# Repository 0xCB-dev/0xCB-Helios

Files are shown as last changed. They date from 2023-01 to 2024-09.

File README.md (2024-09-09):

# 0xCB-Helios

### RP2040 pro micro drop in

| Licence | OSHWA |
| :---: | :---: |
|  | (https://certification.oshwa.org/de000131.html) |

### Official vendors

Purchasing Helios from any vendors listed here directly supports our work. Helios controllers sourced from vendors not listed here and not produced by us will not receive the same level of support and may have varying degrees of quality.

### EU:

Germany: [KeebSupply](https://keeb.supply/products/0xcb-helios)

Germany: [Keycapsss](https://keycapsss.com/keyboard-parts/mcu-controller/257/0xcb-helios-pro-micro/elite-c-compatible-microcontroller-with-rp2040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)

### North America:

America: [Ringer Keys](https://ringerkeys.com/collections/modders-tools/products/0xcb-helios)

Canada: [RNDKBD](https://rndkbd.com/products/0xcb-helios-microcontroller)

#### Flashing

- `qmk clone`
- `cd qmk_firmware`
- To go to bootloader press the reset button longer than 500ms and release. Alternatively you can short the RST pin to GND, as it's wired to the reset button.
- `make 0xcb/helios:default:flash`

### Assembly

The PCBs are assembled at the fab with the production files located in the /kikit/prod/ dir.

### Integration in your own design

We strongly recommend that you take a look at [ebastler's symbol and footprint library for KiCAD](https://github.com/ebastler/marbastlib).
The Helios files are located in the "promicroish" folder with various mounting options to choose from. 
If you need any help integrating Helios into your keyboard PCB, please feel free to contact us.

### PCB

KiCad 7 stable

[Schematic](https://github.com/0xCB-dev/0xcb-Helios/blob/main/rev1.0/helios.pdf)

### Pinout

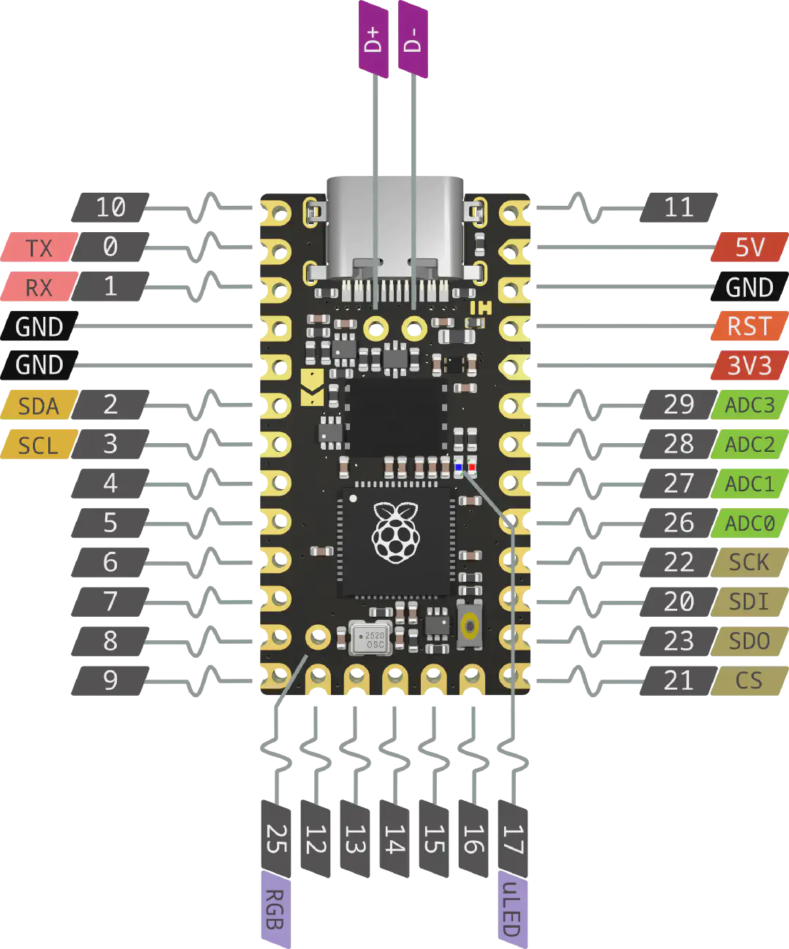
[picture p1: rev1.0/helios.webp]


| GPIO | F1 | F2 | F3 | F4 | F5  | F6 | F7 | F8 | F9 |
| ---- | --- | --- | --- | --- | --- | ---- | ---- | --- | --- |
| 0 | SPI0 RX  | UART0 TX  | I2C0 SDA | PWM0 A | SIO | PIO0 | PIO1 | | USB OVCUR DET |
| 1 | SPI0 CSn | UART0 RX  | I2C0 SCL | PWM0 B | SIO | PIO0 | PIO1 | | USB VBUS DET  |
| 2 | SPI0 SCK | UART0 CTS | I2C1 SDA | PWM1 A | SIO | PIO0 | PIO1 | | USB VBUS EN |
| 3 | SPI0 TX  | UART0 RTS | I2C1 SCL | PWM1 B | SIO | PIO0 | PIO1 | | USB OVCUR DET |
| 4 | SPI0 RX  | UART1 TX  | I2C0 SDA | PWM2 A | SIO | PIO0 | PIO1 | | USB VBUS DET  |
| 5 | SPI0 CSn | UART1 RX  | I2C0 SCL | PWM2 B | SIO | PIO0 | PIO1 | | USB VBUS EN |
| 6 | SPI0 SCK | UART1 CTS | I2C1 SDA | PWM3 A | SIO | PIO0 | PIO1 | | USB OVCUR DET |
| 7 | SPI0 TX  | UART1 RTS | I2C1 SCL | PWM3 B | SIO | PIO0 | PIO1 | | USB VBUS DET  |
| 8 | SPI1 RX  | UART1 TX  | I2C0 SDA | PWM4 A | SIO | PIO0 | PIO1 | | USB VBUS EN |
| 9 | SPI1 CSn | UART1 RX  | I2C0 SCL | PWM4 B | SIO | PIO0 | PIO1 | | USB OVCUR DET |
| 10 | SPI1 SCK | UART1 CTS | I2C1 SDA | PWM5 A | SIO | PIO0 | PIO1 | | USB VBUS DET  |
| 11 | SPI1 TX  | UART1 RTS | I2C1 SCL | PWM5 B | SIO | PIO0 | PIO1 | | USB VBUS EN |
| 12 | SPI1 RX  | UART0 TX  | I2C0 SDA | PWM6 A | SIO | PIO0 | PIO1 | | USB OVCUR DET |
| 13 | SPI1 CSn | UART0 RX  | I2C0 SCL | PWM6 B | SIO | PIO0 | PIO1 | | USB VBUS DET  |
| 14 | SPI1 SCK | UART0 CTS | I2C1 SDA | PWM7 A | SIO | PIO0 | PIO1 | | USB VBUS EN |
| 15 | SPI1 TX  | UART0 RTS | I2C1 SCL | PWM7 B | SIO | PIO0 | PIO1 | | USB OVCUR DET |
| 16 | SPI0 RX  | UART0 TX  | I2C0 SDA | PWM0 A | SIO | PIO0 | PIO1 | | USB VBUS DET  |
| 17 | SPI0 CSn | UART0 RX  | I2C0 SCL | PWM0 B | SIO | PIO0 | PIO1 | | USB VBUS EN |
| 18 | SPI0 SCK | UART0 CTS | I2C1 SDA | PWM1 A | SIO | PIO0 | PIO1 | | USB OVCUR DET |
| 19 | SPI0 TX  | UART0 RTS | I2C1 SCL | PWM1 B | SIO | PIO0 | PIO1 | | USB VBUS DET  |
| 20 | SPI0 RX  | UART1 TX  | I2C0 SDA | PWM2 A | SIO | PIO0 | PIO1 | CLOCK GPIN0  | USB VBUS EN |
| 21 | SPI0 CSn | UART1 RX  | I2C0 SCL | PWM2 B | SIO | PIO0 | PIO1 | CLOCK GPOUT0 | USB OVCUR DET |
| 22 | SPI0 SCK | UART1 CTS | I2C1 SDA | PWM3 A | SIO | PIO0 | PIO1 | CLOCK GPIN1  | USB VBUS DET  |
| 23 | SPI0 TX  | UART1 RTS | I2C1 SCL | PWM3 B | SIO | PIO0 | PIO1 | CLOCK GPOUT1 | USB VBUS EN |
| 24 | SPI1 RX  | UART1 TX  | I2C0 SDA | PWM4 A | SIO | PIO0 | PIO1 | CLOCK GPOUT2 | USB OVCUR DET |
| 25 | SPI1 CSn | UART1 RX  | I2C0 SCL | PWM4 B | SIO | PIO0 | PIO1 | CLOCK GPOUT3 | USB VBUS DET  |
| 26 | SPI1 SCK | UART1 CTS | I2C1 SDA | PWM5 A | SIO | PIO0 | PIO1 | | USB VBUS EN |
| 27 | SPI1 TX  | UART1 RTS | I2C1 SCL | PWM5 B | SIO | PIO0 | PIO1 | | USB OVCUR DET |
| 28 | SPI1 RX  | UART0 TX  | I2C0 SDA | PWM6 A | SIO | PIO0 | PIO1 | | USB VBUS DET  |
| 29 | SPI1 CSn | UART0 RX  | I2C0 SCL | PWM6 B | SIO | PIO0 | PIO1 | | USB VBUS EN |

#### BOM:

| Comment | Designator | Footprint | LCSC |
| --- | --- | --- | --- |
| 4u7 | C1 | Capacitor_SMD:C_0402_1005Metric | C23733 |
| 10u | C2,C3,C4,C5 | Capacitor_SMD:C_0402_1005Metric | C15525 |
| 100n | C6,C11,C12,C13,C14,C15,C16,C17,C18,C19 | Capacitor_SMD:C_0402_1005Metric | C1525 |
| 15p | C7,C8 | Capacitor_SMD:C_0402_1005Metric | C1548 |
| 1u | C9,C10 | Capacitor_SMD:C_0402_1005Metric | C52923 |
| Power LED | D1 | Diode_SMD:D_0402_1005Metric | C130719  |
| User LED | D2 | Diode_SMD:D_0402_1005Metric | C130724  |
| PMEG2010BELD | D3 | 0xcb:SOD882D | C552820  |
| 500mA | F1 | Fuse:Fuse_0603_1608Metric | C210357  |
| 600R | FB1 | Resistor_SMD:R_0402_1005Metric | C160977  |
| USB_C_Receptacle_USB2.0 | J1 | 0xcb:GT-USB-7014C | C963373  |
| 2N7002VC- | Q1,Q2 | Package_TO_SOT_SMD:SOT-563 | C504145  |
| 10k | R1,R2,R3,R11,R17 | Resistor_SMD:R_0402_1005Metric | C25744 |
| 51K | R4,R5,R6 | Resistor_SMD:R_0402_1005Metric | C25794 |
| 5k1 | R7,R8,R16 | Resistor_SMD:R_0402_1005Metric | C25905 |
| 1K | R9 | Resistor_SMD:R_0402_1005Metric | C11702 |
| 1k | R10,R14,R15 | Resistor_SMD:R_0402_1005Metric | C11702 |
| 27R | R12,R13 | Resistor_SMD:R_0402_1005Metric | C25100 |
| SWITCH | SW1 | 0xcb:1.9x2.8mm SW | C589221  |
| USBLC6-2P6 | U1 | Package_TO_SOT_SMD:SOT-666 | C2827693 |
| TLV75533PDQNR | U2 | 0xcb:X2SON-4 | C2861882 |
| W25Q128JVPIQ | U3 | 0xcb:W25Q128JVPIQ | C190862  |
| RP2040 | U4 | Package_DFN_QFN:QFN-56-1EP_7x7mm_P0.4mm_EP3.2x3.2mm | C2040 |
| 74LVC1T45 | U5 | Package_TO_SOT_SMD:SOT-563 | C352970  |
| 12MHz | Y1 | Crystal:Crystal_SMD_2520-4Pin_2.5x2.0mm | C2149204 |

### Credits

The awesome one button reset circuit is based on the one used on the [Sea-picro](https://github.com/joshajohnson/sea-picro) by joshajohnson and this very well written [article](https://acheronproject.com/reset_article_1/reset_article_1/) by the Acheron Project.

Thank you! :heart:

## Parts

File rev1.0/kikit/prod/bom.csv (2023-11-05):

Comment | Designator | Footprint | LCSC
100n | C6,C11,C12,C13,C14,C15,C16,C17,C18,C19 | Capacitor_SMD:C_0402_1005Metric | C1525
USBLC6-2P6 | U1 | Package_TO_SOT_SMD:SOT-666 | C2827693
5.1k | R7,R8,R16 | Resistor_SMD:R_0402_1005Metric | C25905
1k | R9,R10,R14,R15 | Resistor_SMD:R_0402_1005Metric | C11702
12MHz | Y1 | Crystal:Crystal_SMD_2520-4Pin_2.5x2.0mm | C2149204
2N7002VC- | Q1,Q2 | Package_TO_SOT_SMD:SOT-563 | C504145
27 | R12,R13 | Resistor_SMD:R_0402_1005Metric | C25100
10k | R1,R2,R3,R11,R17 | Resistor_SMD:R_0402_1005Metric | C25744
Power LED | D1 | Diode_SMD:D_0402_1005Metric | C130719
10u | C2,C3,C4,C5 | Capacitor_SMD:C_0402_1005Metric | C15525
USB_C_Receptacle_USB2.0 | J1 | 0xcb:GT-USB-7014C | C963373
15p | C7,C8 | Capacitor_SMD:C_0402_1005Metric | C1548
1u | C9,C10 | Capacitor_SMD:C_0402_1005Metric | C52923
51k | R4,R5,R6 | Resistor_SMD:R_0402_1005Metric | C25794
User LED | D2 | Diode_SMD:D_0402_1005Metric | C130724
4.7u | C1 | Capacitor_SMD:C_0402_1005Metric | C23733
500mA | F1 | Fuse:Fuse_0603_1608Metric | C210357
PMEG2010BELD | D3 | 0xcb:SOD882D | C552820
600R | FB1 | Resistor_SMD:R_0402_1005Metric | C160977
TLV75533PDQNR | U2 | 0xcb:X2SON-4 | C2861882
74LVC1T45 | U5 | Package_TO_SOT_SMD:SOT-563 | C352970
W25Q128JVPIQ | U3 | 0xcb:W25Q128JVPIQ | C190862
SWITCH | SW1 | 0xcb:1.9x2.8mm SW | C589221
RP2040 | U4 | Package_DFN_QFN:QFN-56-1EP_7x7mm_P0.4mm_EP3.2x3.2mm | C2040

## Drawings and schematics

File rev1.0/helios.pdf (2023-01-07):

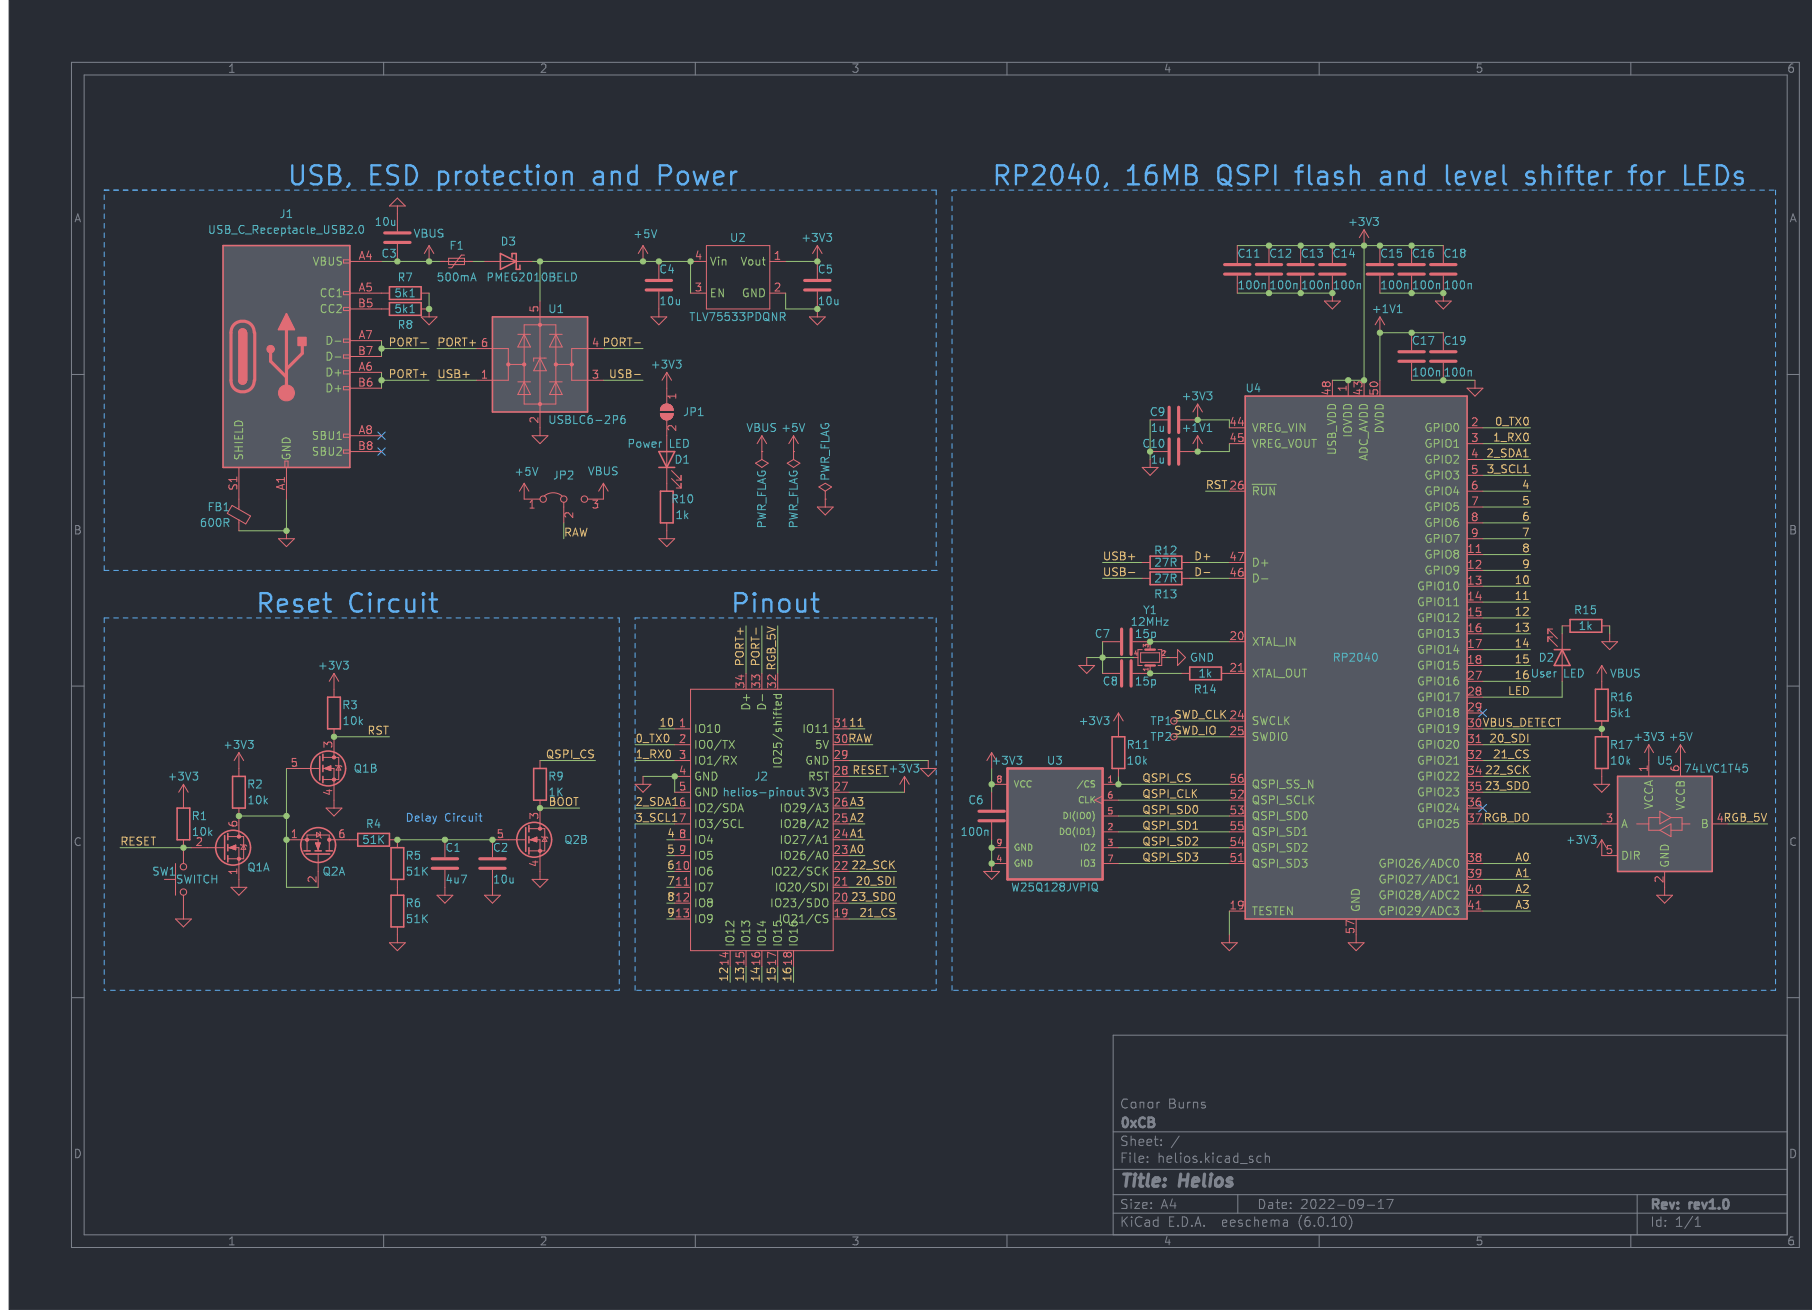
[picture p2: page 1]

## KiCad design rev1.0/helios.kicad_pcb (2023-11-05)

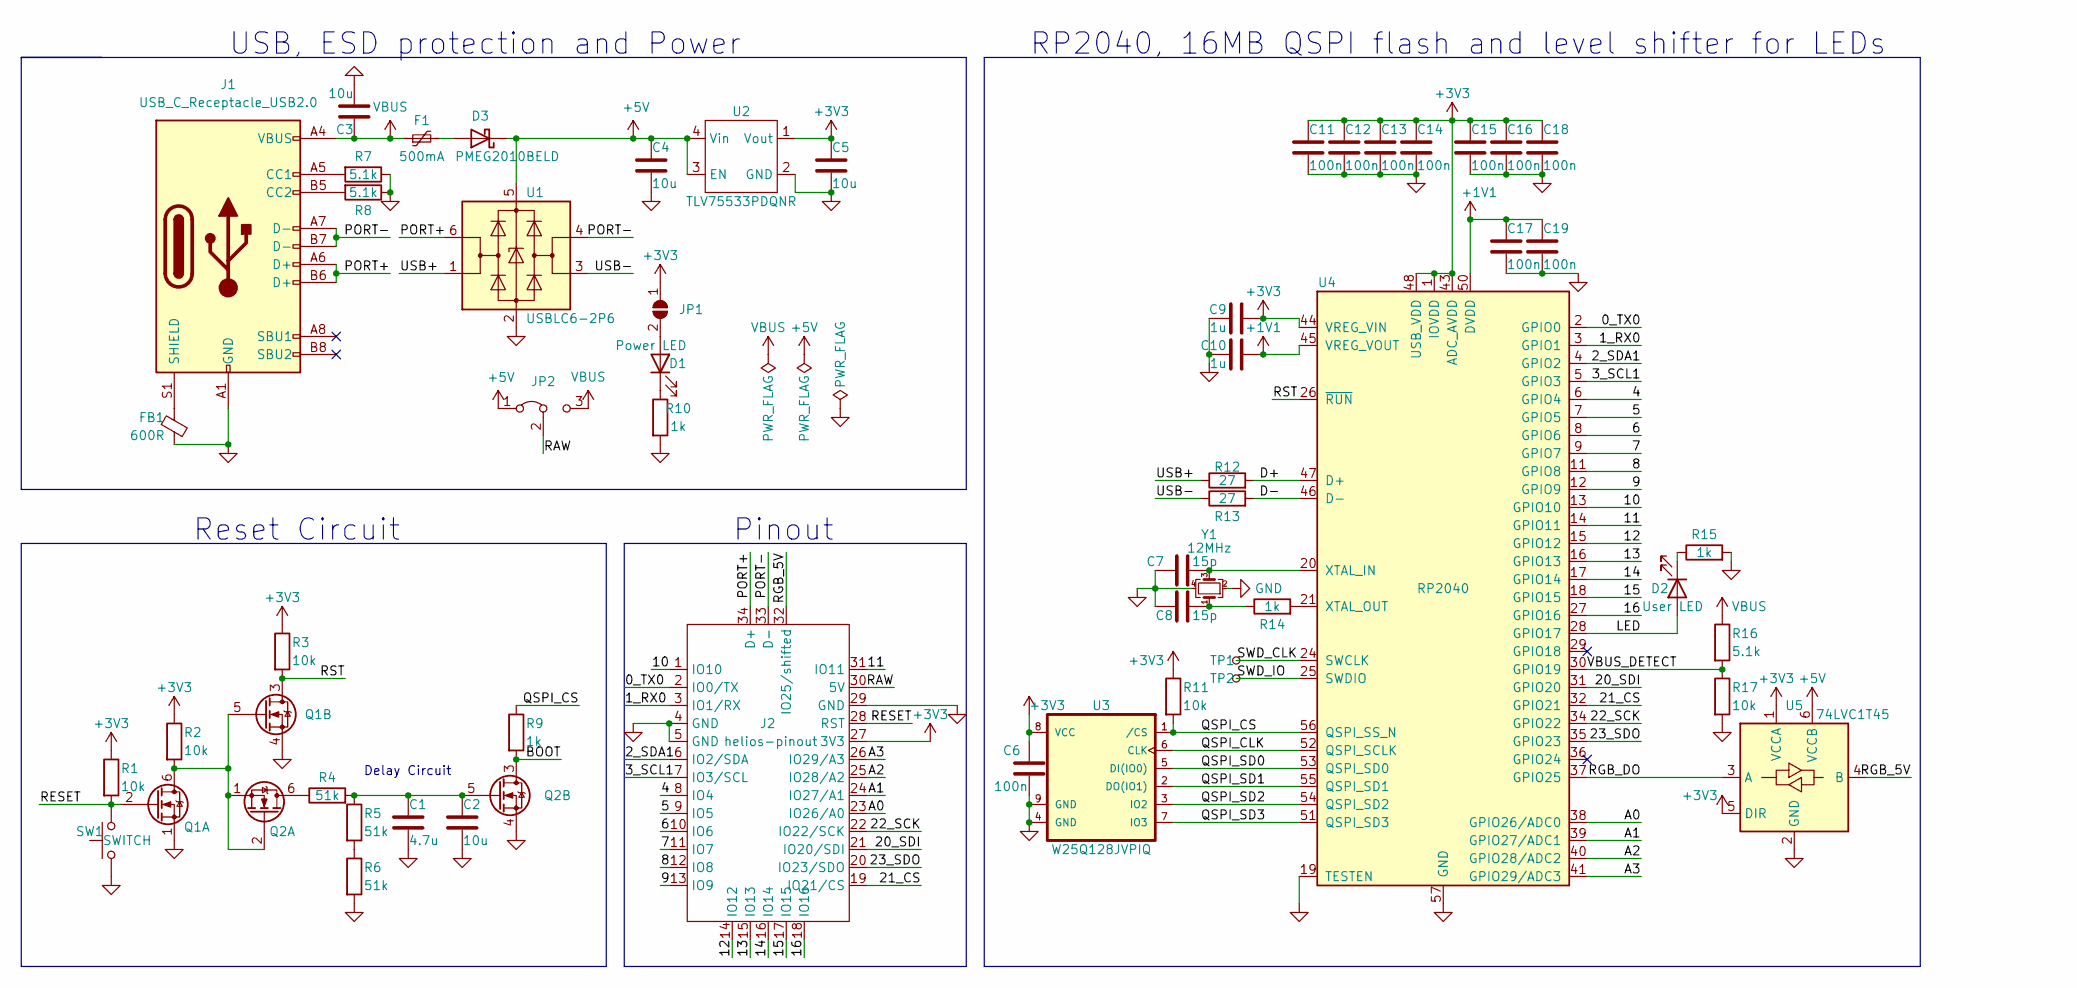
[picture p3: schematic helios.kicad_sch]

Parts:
C1: 4.7u; C_0402_1005Metric; MPN 4.7uF 20% 10V 0402; LCSC C23733
C2, C3, C4, C5: 10u; C_0402_1005Metric; MPN 10uF 20% 10V 0402; LCSC C15525
C6, C11, C12, C13, C14, C15, C16, C17, C18, C19: 100n; C_0402_1005Metric; MPN 100nF 10% 10V 0402; LCSC C1525
C7, C8: 15p; C_0402_1005Metric; MPN 15pF 5% 10V; LCSC C1548
C9, C10: 1u; C_0402_1005Metric; MPN 1uF 20% 10V 0402; LCSC C52923
D1: Power LED; D_0402_1005Metric; MPN B1811URO-20D000113U1930; LCSC C130719
D2: User LED; D_0402_1005Metric; MPN B1811NB--05D000113U1930; LCSC C130724
D3: PMEG2010BELD; SOD882D; MPN PMEG2010BELD,315; JLCPCB_CORRECTION 0; 0; 180
F1: 500mA; Fuse_0603_1608Metric; MPN MF-FSMF050X-2; LCSC C210357
FB1: 600R; R_0402_1005Metric; MPN BLM15PX601SN1D; LCSC C160977
J1: USB_C_Receptacle_USB2.0; GT-USB-7014C; MPN USB4510-03-1-A; LCSC C963373
J2: helios-pinout; helios
JP1: SolderJumper_2_Open; SolderJumper-2_P1.3mm_Open_TrianglePad1.0x1.5mm
JP2: Jumper_3_Bridged12; SolderJumper-3_P1.3mm_Bridged12_RoundedPad1.0x1.5mm_NumberL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
Q1, Q2: 2N7002VC-; SOT-563; MPN 2N7002VC; JLCPCB_CORRECTION 0; 0; 180
R1, R2, R3, R11, R17: 10k; R_0402_1005Metric; MPN 10k 1% 0402; LCSC C25744
R4, R5, R6: 51k; R_0402_1005Metric; MPN 51k 1% 0402; LCSC C25794
R7, R8, R16: 5.1k; R_0402_1005Metric; MPN 5.1k 1% 0402; LCSC C25905
R9, R10, R14, R15: 1k; R_0402_1005Metric; MPN 1k 1% 0402; LCSC C11702
R12, R13: 27; R_0402_1005Metric; MPN 27 1% 0402; LCSC C25100
SW1: SWITCH; 1.9x2.8mm SW; MPN EVP-BL2A1B000; LCSC C589221
TP1: CLK; TestPoint_Pad_D0.8mm
TP2: DIO; TestPoint_Pad_D0.8mm
U1: USBLC6-2P6; SOT-666; MPN USBLC6-2P6; JLCPCB_CORRECTION 0; 0; 270
U2: TLV75533PDQNR; X2SON-4; MPN TLV75533PDQNR; LCSC C2861882
U3: W25Q128JVPIQ; MPN W25Q128JVPIQ; JLCPCB_CORRECTION 0; 0; 270
U4: RP2040; QFN-56-1EP_7x7mm_P0.4mm_EP3.2x3.2mm; MPN SC0914(13); LCSC C2040
U5: 74LVC1T45; SOT-563; MPN SN74LVC1T45DRLR; JLCPCB_CORRECTION 0; 0; 270
Y1: 12MHz; Crystal_SMD_2520-4Pin_2.5x2.0mm; MPN ECS-120-10-36B-CWY-TR3; LCSC C2149204

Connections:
+1V1: C10.2, C17.1, C19.1, U4.23 (DVDD), U4.45 (VREG_VOUT), U4.50 (DVDD)
+3V3: C5.1, C6.1, C9.2, C11.1, C12.1, C13.1, C14.1, C15.1, C16.1, C18.1, J2.27 (3V3), JP1.1 (A), R1.1, R2.1, R3.1, R11.1, U2.1 (Vout), U3.8 (VCC), U4.1 (IOVDD), U4.10 (IOVDD), U4.22 (IOVDD), U4.33 (IOVDD), U4.42 (IOVDD), U4.43 (ADC_AVDD), U4.44 (VREG_VIN), U4.48 (USB_VDD), U4.49 (IOVDD), U5.1 (VCCA), U5.5 (DIR)
+5V: C4.1, D3.1 (K), JP2.1 (A), U1.5 (VBUS), U2.3 (EN), U2.4 (Vin), U5.6 (VCCB)
/0_TX0: J2.2 (IO0/TX), U4.2 (GPIO0)
/1_RX0: J2.3 (IO1/RX), U4.3 (GPIO1)
/2_SDA1: J2.6 (IO2/SDA), U4.4 (GPIO2)
/3_SCL1: J2.7 (IO3/SCL), U4.5 (GPIO3)
/4: J2.8 (IO4), U4.6 (GPIO4)
/5: J2.9 (IO5), U4.7 (GPIO5)
/6: J2.10 (IO6), U4.8 (GPIO6)
/7: J2.11 (IO7), U4.9 (GPIO7)
/8: J2.12 (IO8), U4.11 (GPIO8)
/9: J2.13 (IO9), U4.12 (GPIO9)
/10: J2.1 (IO10), U4.13 (GPIO10)
/11: J2.31 (IO11), U4.14 (GPIO11)
/12: J2.14 (IO12), U4.15 (GPIO12)
/13: J2.15 (IO13), U4.16 (GPIO13)
/14: J2.16 (IO14), U4.17 (GPIO14)
/15: J2.17 (IO15), U4.18 (GPIO15)
/16: J2.18 (IO16), U4.27 (GPIO16)
/20_SDI: J2.21 (IO20/SDI), U4.31 (GPIO20)
/21_CS: J2.19 (IO21/CS), U4.32 (GPIO21)
/22_SCK: J2.22 (IO22/SCK), U4.34 (GPIO22)
/23_SDO: J2.20 (IO23/SDO), U4.35 (GPIO23)
/A0: J2.23 (IO26/A0), U4.38 (GPIO26/ADC0)
/A1: J2.24 (IO27/A1), U4.39 (GPIO27/ADC1)
/A2: J2.25 (IO28/A2), U4.40 (GPIO28/ADC2)
/A3: J2.26 (IO29/A3), U4.41 (GPIO29/ADC3)
/BOOT: Q2.3 (D), R9.2
/D+: R12.2, U4.47 (D+)
/D-: R13.2, U4.46 (D-)
/LED: D2.2 (A), U4.28 (GPIO17)
/PORT+: J1.A6 (D+), J1.B6 (D+), J2.34 (D+), U1.6 (I/O1)
/PORT-: J1.A7 (D-), J1.B7 (D-), J2.33 (D-), U1.4 (I/O2)
/QSPI_CLK: U3.6 (CLK), U4.52 (QSPI_SCLK)
/QSPI_CS: R9.1, R11.2, U3.1 (/CS), U4.56 (QSPI_SS_N)
/QSPI_SD0: U3.5 (DI(IO0)), U4.53 (QSPI_SD0)
/QSPI_SD1: U3.2 (DO(IO1)), U4.55 (QSPI_SD1)
/QSPI_SD2: U3.3 (IO2), U4.54 (QSPI_SD2)
/QSPI_SD3: U3.7 (IO3), U4.51 (QSPI_SD3)
/RAW: J2.30 (5V), JP2.2 (C)
/RESET: J2.28 (RST), Q1.2 (G), R1.2, SW1.2
/RGB_5V: J2.32 (IO25/shifted), U5.4 (B)
/RGB_DO: U4.37 (GPIO25), U5.3 (A)
/RST: Q1.3 (D), R3.2, U4.26 (~RUN)
/SWD_CLK: TP1.1, U4.24 (SWCLK)
/SWD_IO: TP2.1, U4.25 (SWDIO)
/USB+: R12.1, U1.1 (I/O1)
/USB-: R13.1, U1.3 (I/O2)
/VBUS_DETECT: R16.2, R17.1, U4.30 (GPIO19)
GND: C1.2, C2.2, C3.2, C4.2, C5.2, C6.2, C7.1, C8.1, C9.1, C10.1, C11.2, C12.2, C13.2, C14.2, C15.2, C16.2, C17.2, C18.2, C19.2, FB1.2, J1.A1 (GND), J1.A12 (GND), J1.B1 (GND), J1.B12 (GND), J2.4 (GND), J2.5 (GND), J2.29 (GND), Q1.1 (S), Q1.4 (S), Q2.4 (S), R6.2, R7.1, R8.1, R10.2, R15.2, R17.2, SW1.1, U1.2 (GND), U2.2 (GND), U2.5 (TP), U3.4 (GND), U3.9 (GND), U4.19 (TESTEN), U4.57 (GND), U5.2 (GND), Y1.2, Y1.4
unnamed: C8.2, R14.1, Y1.1
unnamed: D1.2 (A), JP1.2 (B)
unnamed: D1.1 (K), R10.1
unnamed: D2.1 (K), R15.1
unnamed: D3.2 (A), F1.2
unnamed: J1.A5 (CC1), R7.2
unnamed: J1.B5 (CC2), R8.2
unnamed: FB1.1, J1.S1 (SHIELD)
unnamed: Q1.5 (G), Q1.6 (D), Q2.1 (S), Q2.2 (G), R2.2
unnamed: Q2.6 (D), R4.1
unnamed: C1.1, C2.1, Q2.5 (G), R4.2, R5.1
unnamed: R5.2, R6.1
unnamed: C7.2, U4.20 (XTAL_IN), Y1.3
unnamed: R14.2, U4.21 (XTAL_OUT)
VBUS: C3.1, F1.1, J1.A4 (VBUS), J1.A9 (VBUS), J1.B4 (VBUS), J1.B9 (VBUS), JP2.3 (B), R16.1

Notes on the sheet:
Delay Circuit
USB, ESD protection and Power
RP2040, 16MB QSPI flash and level shifter for LEDs
Reset Circuit
Pinout

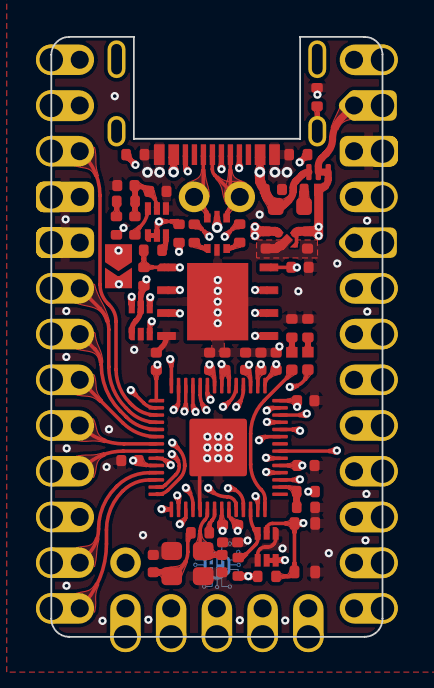
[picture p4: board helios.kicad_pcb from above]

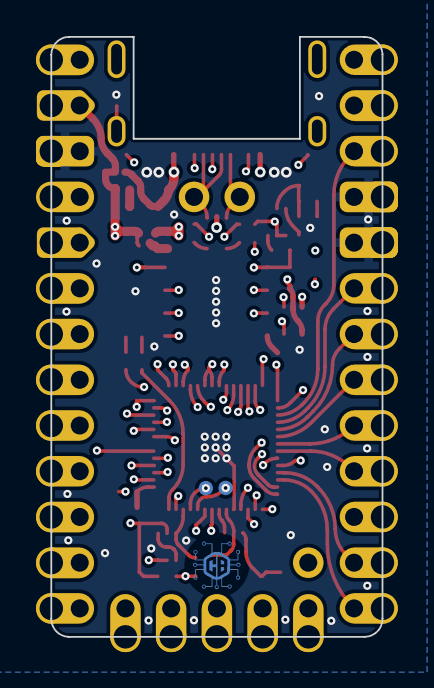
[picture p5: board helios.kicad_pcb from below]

Board: 4 copper layers, 18.4 x 33.3 mm, 56 parts (2 on the bottom side), 66 nets.

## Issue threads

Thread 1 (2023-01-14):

Recommended settings for JLCPCB

idank, 2023-01-14:
I was able to get a gerber/bom/cpl loaded properly on jlc but the costs are extremely high. Do you have any suggestions on how to bring those down a bit? Or is this not economically viable to order in small quantities? (a few dozen)

FYI main reason I look into it is because keeb.supply doesn't ship outside the EU.

Jakob170201, 2023-01-14:
Hey! Thank you for your interest! We can get such low prices, because we order in large quantities. I'm talking over 150 controllers at a time. With jlc you have a lot of fixed fees. When you order more the fees don't get more expensive resulting In cheaper costs overall. Things like Enig finish also cost extra.

We currently have a shipment of Helios controllers on the way to Ringerkeys in the US. Those will go InStock soon, so if you will be able to get them worldwide shortly.

idank, 2023-01-14:
Yeah that makes sense. I'm still curious how cheap one can get with optimal settings, for example I noticed this increased costs a bit when adding assembly:

> Your PCB size is 33.02mm*17.78mm, JLCPCB will help you add edge rails and enlarge
>
> the size to 71.02mm*71.78mm.

I guess a complete panel will be more cost effective?

Jakob170201, 2023-01-14:
Yes we order them in panels of 10 controllers. The files are also here in the GitHub.

idank, 2023-01-15:
Oh it's under rev1.0/kikit, nice! Are there any considerations / settings that need to be picked to get one made from JLCPCB?

opaldes, 2023-04-26:
Dont forget that each pcb holds 10 Helios Controller and you order 5pcbs here so 50 Helios. Standard costs me around 6 euro each without shipping question is do you need 50 Helios.

Ardakilic, 2023-06-09:
Hello, can you confirm the board is indeed 4 layers? Thanks!

Jakob170201, 2023-06-09:
Yes. Helios is a 4 layer board.

Closed 2023-11-04.

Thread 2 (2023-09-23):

Flashing does not work

bfloch, 2023-09-23:
Got the device via Keebd.
The instructions in the repo do not work. Instead I went with the .hex file from the Keebd website (cobra_default.hex). It copies the .uf2 to the drive but then nothing.
Pressing the reset button or not does not make a difference - it always goes back into bootloader mode.

Can you help guide me through the process - or point to clearer instructions? Thanks.

medoix, 2023-09-23:
Helios firmware files end in .uf2 not .hex (due to running the RP2040 chip) so it sounds like you downloaded the wrong file.

[QMK has converters](https://docs.qmk.fm/#/feature_converters?id=converters) that will build the right firmware file.

Also when the Helios enters bootloader mode a volume will be mounted and you simply need to drag/drop the .uf2 file onto it to program the controller.

bfloch, 2023-09-24:
Ok got it working.
```
qmk config user.keymap=stateoff  # Can be anything / username
qmk config user.keyboard=contra
# Generate json and download at https://config.qmk.fm/#/contra/LAYOUT_planck_mit
# Plug in Helios (use button if not in bootloader mode)
qmk flash -c generated.json  -e CONVERT_TO=helios
```
This made it for me. Thanks for the hints.

Closed 2023-09-24.

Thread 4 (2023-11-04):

Info about bootloader access when reset button is inaccessible

tonykakuuu, 2023-11-04:
Some boards require you to solder the board upside down, making the reset button inaccessible. For these boards, the user needs to short RST and GND to access the bootloader. Please include this info at least somewhere on the README page. I know you can deduce it from the pinout but I'm pretty sure users who don't know much about circuitry are going to end up wondering about alternative ways of flashing their Helios.

Conor-Burns, 2023-11-04:
Thanks for the info - I'll add it to the readme.

Closed 2023-11-04.

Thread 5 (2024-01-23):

Board won't enter bootloader mode

ethangamma24, 2024-01-23:
Hi there! I just got two of these boards as part of a corner keyboard kit. I've been attempting to flash firmware to them, but the boards won't enter bootloader mode. When I plug them into my computer (M1 MacBook Pro) I see the device listed as "RPI-RP2" with two files inside: INDEX.HTM and INFO_UF2.TXT. When I press and hold the reset button for the >500ms specified, the device briefly disappears, then reappears in the exact same manner. I have attempted to enter bootloader mode by shorting the RST and GND pins that are next to each other, and still nothing. I've tried both boards with the same results. I've done lots of googling, but am unable to find anyone else with these issues. Any ideas as to what the problem might be and how it can be solved? Thanks!

Conor-Burns, 2024-01-23:
Did you buy the board through any of the vendors listed in here: https://docs.keeb.supply/0xcb-helios/infos/

ethangamma24, 2024-01-23:
I did not, it was purchased through https://keebd.com/en-us.

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

Conor-Burns, 2024-01-23:
Yeah sorry. We are getting a lot of support requests from customers from keebd. Since we are not supplying keebd with the helioses and they seem to have a lot of quality issues we stopped giving customer support to helioses not bought through official vendors. I hope that you can understand that.

Best of luck!

ethangamma24, 2024-01-23:
Totally understood, thank you so much for the reply!! I'll try and get a refund ASD purchase the boards through one of your vendors.

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

medoix, 2024-01-23:
@ethangamma24 have you opened and read the INDEX.HTM and INFO_UF2.TXT files you mentioned? When you see these files, the Helios is in bootloader mode and ready to accept the .uf2 firmware file. This is not a quality issue.

ethangamma24, 2024-01-23:
I have indeed opened and read them, but the files are locked and I'm unable to move any files into the drive. When I attempt to flash with QMK, the program errors out stating that the drive is in read only mode.

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

medoix, 2024-01-23:
Could this be computer related? Could you test one on a different PC. When the Helios brings up the File Explorer that indicates that it is in bootloader mode and ready for the firmware as you noted. Once you drag the uf2 firmware onto it the File Explorer will stop popping up on connection and will instead run the firmware in keyboard mode.

ethangamma24, 2024-01-23:
Actually now that I think about it, it could be the computer not allowing it to open in anything other than read only (there are some administrative restrictions on the machine). I'll try later this evening on another device.

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

Closed 2024-01-23.

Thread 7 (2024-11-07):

Сompatibility with Sea-Picro

bekkazy-k, 2024-11-07:
I'm new to this. I have a keyboard based on [Sea-Picro](https://github.com/joshajohnson/sea-picro). Can I replace the microcontroller with Helios without any changes, or do I need to reassign the pins?

Conor-Burns, 2024-11-07:
They are both using the rp2040_ce standard so they are pin compatible.

Closed 2024-11-07.

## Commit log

2022-09-17 schematic, pcb and BOM done
    [helios.kicad_pcb, helios.kicad_sch]
2022-09-17 production files for ptotos
    [Helios-BOM.xlsx, helios.kicad_pcb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]
2022-09-18 added prod files for jlcpcb
    [Helios-BOM.xlsx, bom.csv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]
2022-09-19 fixed jlc issue
    [helios-panel-CmtUser.gbr, helios-panel-CuBottom.gbl, helios-panel-EdgeCuts.gm1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]
2022-09-20 updated assembly files again
    [helios-panel-CmtUser.gbr, helios-panel-CuBottom.gbl, helios-panel-EdgeCuts.gm1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]
2022-10-12 fixed proto mistakes, revised power circuit and added option to use vbus on the 5v pin
    [helios.kicad_pcb]
2022-10-20 prod files
    [bom.csv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]
2022-12-15 production files
    [helios-panel-CmtUser.gbr, helios-panel-CuBottom.gbl, helios-panel-EdgeCuts.gm1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]
2023-01-07 added KiCAD files
2023-05-29 add castellated holes
    [helios-CmtUser.gbr, helios-CuBottom.gbl, helios-CuTop.gtl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]
2023-06-03 fix tabs in pads
    [helios-panel-CmtUser.gbr, helios-panel-CuBottom.gbl, helios-panel-EdgeCuts.gm1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]
2023-06-04 change over to mouse bites
    [helios-panel-CmtUser.gbr, helios-panel-CuBottom.gbl, helios-panel-EdgeCuts.gm1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]
2023-08-03 widen tabs
    [bom.csv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]
2023-08-03 widen tabs even more
    [helios-panel-CmtUser.gbr, helios-panel-CuBottom.gbl, helios-panel-CuTop.gtl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]
2023-08-29 manu change
    [bom.csv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]
2023-11-05 Fix readme and add current prod
    [bom.csv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]
